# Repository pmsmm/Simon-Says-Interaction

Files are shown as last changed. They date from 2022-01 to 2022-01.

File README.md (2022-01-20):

# Simon Says Interaction

The Simon Says Interaction is a mini game that was developed for my Master Thesis "Developing a Support Infrastructure for an Escape The Room and Peddy Paper Games".

This mini game, or interaction as I so call it, was developed to be part of an Escape the Room game that was also developed as part of my thesis. Since this interaction can work as a standalone mini game I decided to place it here for anyone interested in using it.

## List of Components

- Otemu Mechanical Switch (12x);
- Diode 1n4148 (12x);
- Red LED (1x);
- Green LED (1x);
- Piezzo Speaker (1x);
- 7-Segment Display (1x);
- 220Ω Resistor (10x);
- Arduino Nano (1x);

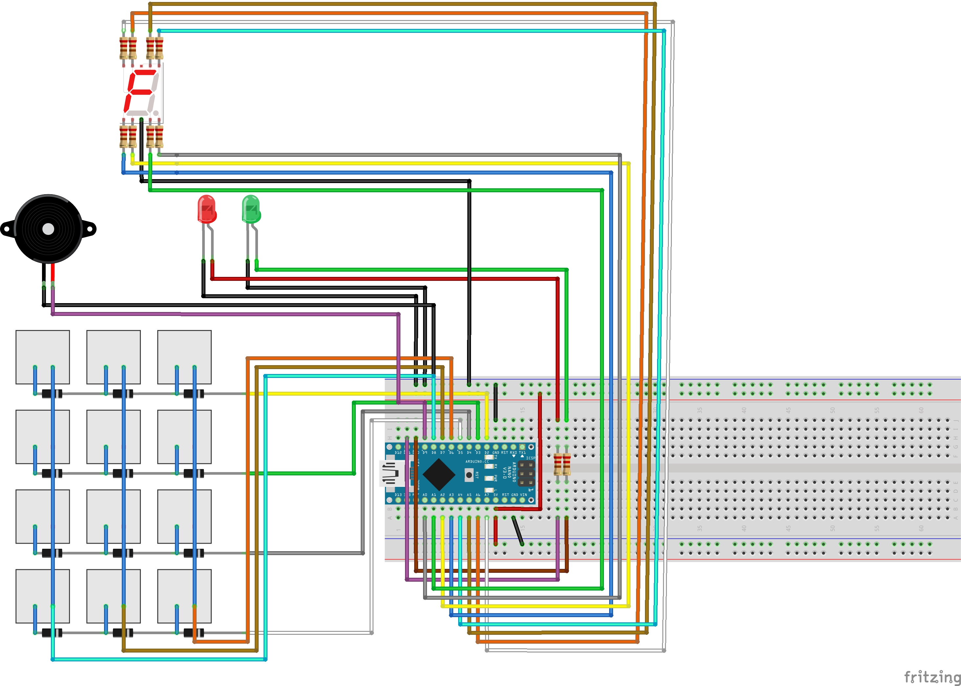
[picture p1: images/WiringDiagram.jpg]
Wiring Diagram


In order to fully assemble the Interaction, so as to look like the picture below, you will also need to 3D Print the enclosure which is divided into two parts that can be found [here](enclosure/). Additionally, you will also need to 3D Print the keycaps which were not designed by me but can be found in [Thingiverse](https://www.thingiverse.com/thing:2783650).

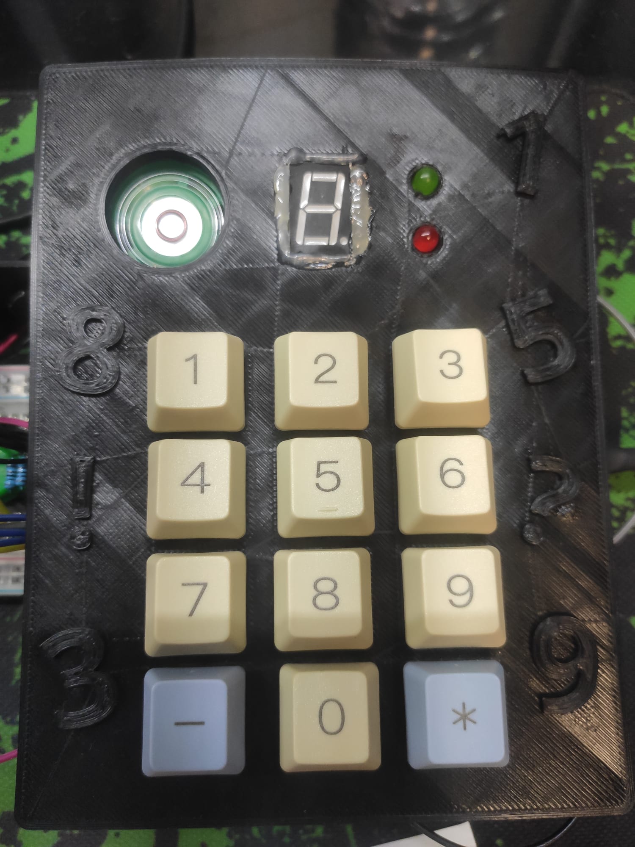
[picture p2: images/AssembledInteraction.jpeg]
Assembled Interaction


## The Purpose of The Game

The Simon Says Interaction is the classic memory game mixed up with pattern recognition in a light sense. The way this mini game works is that on the 7-Segment display, a series of numbers will appear in increasingly hard sequences that have to be reproduced but the tricky part that the player will have to realize is that only the numbers that appear with the dot on the display lit are the ones that should be introduced.

### Example

Lets say for example that the following numbers appear on the display:

- > 7 9. 3 5. 0. 3 6 1.

What the player would have to introduce in order to solve this mini game would be the numbers 9, 5, 0 and 1 in this order. When they achieve this the green LED will light up and a success sound will be played to symbolize that the player has won.

## Intructions 

First start by uploading the code to your Arduino Nano (This is the one I used so I can only guarantee proper working with this micro-controller).

### Starting the Game

To start the game you must first type in the Arduino IDE serial monitor the following:

- > COM:START;ID:123456789

This command will then print in the Serial Monitor the solution of the game which then needs to be introduced using the keypad. If the introduced code is correct then the following message will appear in the serial monitor:

- > COM:INTERACTION_SOLVED;MSG:User Introduced Correct Patterns;PNT:1500

## Warning

The source code for this interaction contains a lot of logic that was made to communicate with the infrastructure that was developed for my thesis and therefor it is not as clean as it could be when compared to a mini game that is developed with the intent of being used by the Arduino IDE directly.

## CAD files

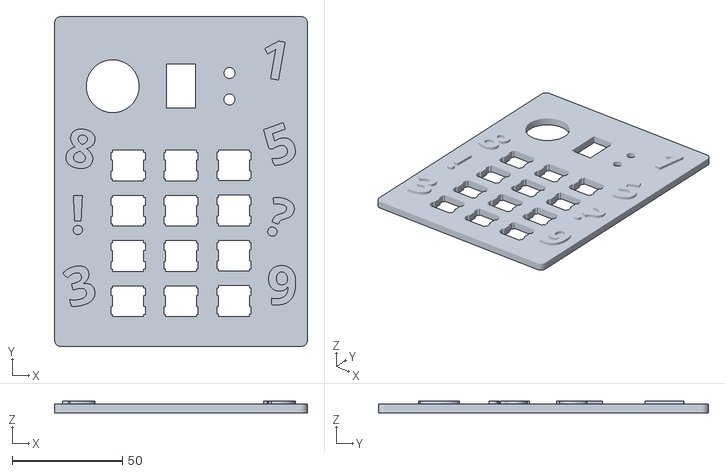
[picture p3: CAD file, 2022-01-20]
enclosure/Simon Says Plate.stl
115.0 x 150.0 x 5.50

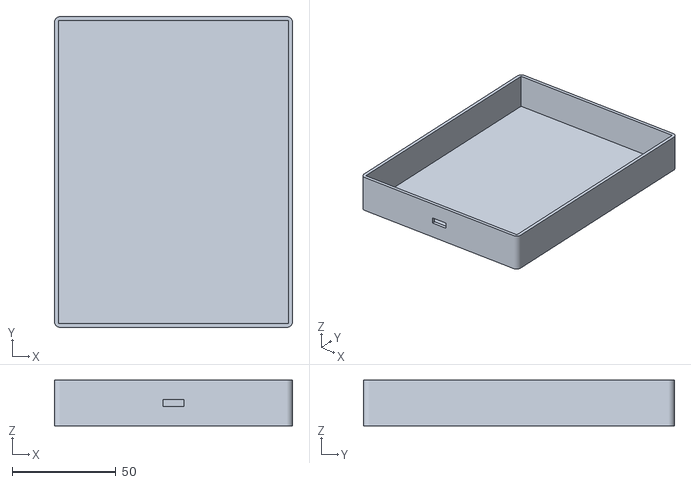
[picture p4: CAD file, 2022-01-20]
enclosure/Simon Says Case.stl
115.0 x 150.0 x 22.0

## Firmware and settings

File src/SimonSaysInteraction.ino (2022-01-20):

#include "pitches.h"
/*
  Displays the numbers 0-9 on the display, at one second intervals
  Implemented using 5611AH - 8-segment display
  Pin assignment for 5611AH
     G  F com A  B
   __|__|__|__|__|__
  | 10  9  8  7  6  |
  |  1  2  3  4  5  |
   --|--|--|--|--|--
     E  D com C  P

  A=7,B=6,C=4,D=2,E=1,F=9,G=10,P=5,com=GND
  LED segment assignment corresponding to pins
    A
   ---
  F |   | B
  | G |
   ---
  E |   | C
  |   |
   ---  . P
    D
*/

const uint8_t pinA = 15;
const uint8_t pinB = 16;
const uint8_t pinC = 11;
const uint8_t pinD = 10;
const uint8_t pinE = 9;
const uint8_t pinF = 14;
const uint8_t pinG = 13;
const uint8_t pinP = 12;
const uint8_t redLED = A3;
const uint8_t greenLED = A4;
const uint8_t buzzer = A5;

byte rows[] = {2, 3, 4};
const int rowCount = sizeof(rows) / sizeof(rows[0]);

byte cols[] = {5, 6, 7, 8};
const int colCount = sizeof(cols) / sizeof(cols[0]);

byte keys[colCount][rowCount];
uint8_t numbers[colCount][rowCount] = {
  {10, 0, 10},
  {7, 8, 9},
  {4, 5, 6},
  {1, 2, 3}
};

struct NUMBER {
  uint8_t number;
  bool isValidNumber;
};

NUMBER firstLevel[4];
NUMBER firstLevelSolution[2];
NUMBER secondLevel[8];
NUMBER secondLevelSolution[4];
NUMBER thirdLevel[12];
NUMBER thirdLevelSolution[6];
NUMBER fourthLevel[16];
NUMBER fourthLevelSolution[8];

uint8_t currentLevel = 1;
uint8_t currentLevelIndex = 0;
bool sequencePlayedOnce = false;

bool INTERACTION_SOLVED, INTERACTION_RUNNING;

void setup() {
  Serial.begin(9600);
  randomSeed(analogRead(A0));
  pinMode(pinA, OUTPUT);
  pinMode(pinB, OUTPUT);
  pinMode(pinC, OUTPUT);
  pinMode(pinD, OUTPUT);
  pinMode(pinE, OUTPUT);
  pinMode(pinF, OUTPUT);
  pinMode(pinG, OUTPUT);
  pinMode(pinP, OUTPUT);
  pinMode(greenLED, OUTPUT);
  pinMode(redLED, OUTPUT);
}

void loop() {
  if (!Serial) {
    Serial.begin(9600);
  }
  if (Serial.available()) {
    processSerialMessage();
  }
  if (INTERACTION_SOLVED == false && INTERACTION_RUNNING == true) {
    gameLoop();
  }
}

void gameLoop() {
  if (!sequencePlayedOnce) {
    Serial.println("Lighting Up Sequence");
    if (currentLevel == 1) {
      Serial.println("Lighting Up Sequence For Level 1");
      for (uint8_t i = 0; i < 4; i++) {
        printNumber(firstLevel[i]);
      }
    }
    else if (currentLevel == 2) {
      Serial.println("Lighting Up Sequence For Level 2");
      for (uint8_t i = 0; i < 8; i++) {
        printNumber(secondLevel[i]);
      }
    }
    else if (currentLevel == 3) {
      Serial.println("Lighting Up Sequence For Level 3");
      for (uint8_t i = 0; i < 12; i++) {
        printNumber(thirdLevel[i]);
      }
    }
    else if (currentLevel == 4) {
      Serial.println("Lighting Up Sequence For Level 4");
      for (uint8_t i = 0; i < 16; i++) {
        printNumber(fourthLevel[i]);
      }
    }
    sequencePlayedOnce = true;
  }
  checkPressedButton(readMatrixAndReturnPressedKey());
  delay(225);
}

void checkPressedButton(int8_t selectedNumber) {
  if (selectedNumber == -1) {
    return;
  }
  NUMBER number;
  number.number = selectedNumber;
  printNumber(number);
  if (currentLevel == 1) {
    if (selectedNumber == firstLevelSolution[currentLevelIndex].number) {
      if (currentLevelIndex == 1) {
        currentLevelIndex = 0;
        currentLevel++;
        sequencePlayedOnce = false;
        digitalWrite(greenLED, HIGH);
        tone(buzzer, NOTE_FS7, 1500);
        delay(1500);
        digitalWrite(greenLED, LOW);
      } else {
        currentLevelIndex++;
      }
    } else {
      sequencePlayedOnce = false;
      digitalWrite(redLED, HIGH);
      tone(buzzer, NOTE_GS2, 1500);
      delay(1500);
      digitalWrite(redLED, LOW);
      currentLevelIndex = 0;
      currentLevel = 1;
    }
  } else if (currentLevel == 2) {
    if (selectedNumber == secondLevelSolution[currentLevelIndex].number) {
      if (currentLevelIndex == 3) {
        currentLevelIndex = 0;
        currentLevel++;
        sequencePlayedOnce = false;
        digitalWrite(greenLED, HIGH);
        tone(buzzer, NOTE_FS7, 1500);
        delay(1500);
        digitalWrite(greenLED, LOW);
      } else {
        currentLevelIndex++;
      }
    } else {
      sequencePlayedOnce = false;
      digitalWrite(redLED, HIGH);
      tone(buzzer, NOTE_GS2, 1500);
      delay(1500);
      digitalWrite(redLED, LOW);
      currentLevelIndex = 0;
      currentLevel = 1;
    }
  } else if (currentLevel == 3) {
    if (selectedNumber == thirdLevelSolution[currentLevelIndex].number) {
      if (currentLevelIndex == 5) {
        currentLevelIndex = 0;
        currentLevel++;
        sequencePlayedOnce = false;
        digitalWrite(greenLED, HIGH);
        tone(buzzer, NOTE_FS7, 1500);
        delay(1500);
        digitalWrite(greenLED, LOW);
      } else {
        currentLevelIndex++;
      }
    } else {
      sequencePlayedOnce = false;
      digitalWrite(redLED, HIGH);
      tone(buzzer, NOTE_GS2, 1500);
      delay(1500);
      digitalWrite(redLED, LOW);
      currentLevelIndex = 0;
      currentLevel = 1;
    }
  } else if (currentLevel == 4) {
    if (selectedNumber == fourthLevelSolution[currentLevelIndex].number) {
      if (currentLevelIndex == 7) {
        currentLevelIndex = 0;
        currentLevel++;
        sequencePlayedOnce = false;
        digitalWrite(greenLED, HIGH);
        tone(buzzer, NOTE_FS7, 1500);
        delay(1500);
        digitalWrite(greenLED, LOW);
        checkWinning();
      } else {
        currentLevelIndex++;
      }
    } else {
      sequencePlayedOnce = false;
      digitalWrite(redLED, HIGH);
      tone(buzzer, NOTE_GS2, 1500);
      delay(1500);
      digitalWrite(redLED, LOW);
      currentLevelIndex = 0;
      currentLevel = 1;
    }
  }
}


void printNumber(NUMBER numberToPrint) {
  Serial.println(numberToPrint.number);
  if (numberToPrint.number == 1) {
    digitalWrite(pinA, LOW);
    digitalWrite(pinB, HIGH);
    digitalWrite(pinC, HIGH);
    digitalWrite(pinD, LOW);
    digitalWrite(pinE, LOW);
    digitalWrite(pinF, LOW);
    digitalWrite(pinG, LOW);
    digitalWrite(pinP, LOW);
  } else if (numberToPrint.number == 2) {
    digitalWrite(pinA, HIGH);
    digitalWrite(pinB, HIGH);
    digitalWrite(pinC, LOW);
    digitalWrite(pinD, HIGH);
    digitalWrite(pinE, HIGH);
    digitalWrite(pinF, LOW);
    digitalWrite(pinG, HIGH);
    digitalWrite(pinP, LOW);
  } else if (numberToPrint.number == 3) {
    digitalWrite(pinA, HIGH);
    digitalWrite(pinB, HIGH);
    digitalWrite(pinC, HIGH);
    digitalWrite(pinD, HIGH);
    digitalWrite(pinE, LOW);
    digitalWrite(pinF, LOW);
    digitalWrite(pinG, HIGH);
    digitalWrite(pinP, LOW);
  } else if (numberToPrint.number == 4) {
    digitalWrite(pinA, LOW);
    digitalWrite(pinB, HIGH);
    digitalWrite(pinC, HIGH);
    digitalWrite(pinD, LOW);
    digitalWrite(pinE, LOW);
    digitalWrite(pinF, HIGH);
    digitalWrite(pinG, HIGH);
    digitalWrite(pinP, LOW);
  } else if (numberToPrint.number == 5) {
    digitalWrite(pinA, HIGH);
    digitalWrite(pinB, LOW);
    digitalWrite(pinC, HIGH);
    digitalWrite(pinD, HIGH);
    digitalWrite(pinE, LOW);
    digitalWrite(pinF, HIGH);
    digitalWrite(pinG, HIGH);
  } else if (numberToPrint.number == 6) {
    digitalWrite(pinA, HIGH);
    digitalWrite(pinB, LOW);
    digitalWrite(pinC, HIGH);
    digitalWrite(pinD, HIGH);
    digitalWrite(pinE, HIGH);
    digitalWrite(pinF, HIGH);
    digitalWrite(pinG, HIGH);
    digitalWrite(pinP, LOW);
  } else if (numberToPrint.number == 7) {
    digitalWrite(pinA, HIGH);
    digitalWrite(pinB, HIGH);
    digitalWrite(pinC, HIGH);
    digitalWrite(pinD, LOW);
    digitalWrite(pinE, LOW);
    digitalWrite(pinF, LOW);
    digitalWrite(pinG, LOW);
    digitalWrite(pinP, LOW);
  } else if (numberToPrint.number == 8) {
    digitalWrite(pinA, HIGH);
    digitalWrite(pinB, HIGH);
    digitalWrite(pinC, HIGH);
    digitalWrite(pinD, HIGH);
    digitalWrite(pinE, HIGH);
    digitalWrite(pinF, HIGH);
    digitalWrite(pinG, HIGH);
    digitalWrite(pinP, LOW);
  } else if (numberToPrint.number == 9) {
    digitalWrite(pinA, HIGH);
    digitalWrite(pinB, HIGH);
    digitalWrite(pinC, HIGH);
    digitalWrite(pinD, HIGH);
    digitalWrite(pinE, LOW);
    digitalWrite(pinF, HIGH);
    digitalWrite(pinG, HIGH);
    digitalWrite(pinP, LOW);
  } else if (numberToPrint.number == 0) {
    digitalWrite(pinA, HIGH);
    digitalWrite(pinB, HIGH);
    digitalWrite(pinC, HIGH);
    digitalWrite(pinD, HIGH);
    digitalWrite(pinE, HIGH);
    digitalWrite(pinF, HIGH);
    digitalWrite(pinG, LOW);
    digitalWrite(pinP, LOW);
  }
  if (numberToPrint.isValidNumber) {
    digitalWrite(pinP, HIGH);
  }
  delay(1000);
  shutdown7SegmentDisplay();
  delay(100);
}

void shutdown7SegmentDisplay() {
  digitalWrite(pinA, LOW);
  digitalWrite(pinB, LOW);
  digitalWrite(pinC, LOW);
  digitalWrite(pinD, LOW);
  digitalWrite(pinE, LOW);
  digitalWrite(pinF, LOW);
  digitalWrite(pinG, LOW);
  digitalWrite(pinP, LOW);
}

void generateRandomNumberStructs(NUMBER numbers[], NUMBER validNumbers[], uint8_t arraySize) {
  uint8_t i = 0;
  for (i = 0; i < arraySize / 2; i++) {
    NUMBER randomNumber;
    randomNumber.number = random(0, 10);
    randomNumber.isValidNumber = true;
    numbers[i] = randomNumber;
  }
  for (i = arraySize / 2; i < arraySize; i++) {
    NUMBER randomNumber;
    randomNumber.number = random(0, 10);
    randomNumber.isValidNumber = false;
    numbers[i] = randomNumber;
  }
  for (i = 0; i < arraySize; i++) {
    uint8_t n = random(0, arraySize);
    NUMBER temp = numbers[n];
    numbers[n] = numbers[i];
    numbers[i] = temp;
  }
  uint8_t solutionArrayIndex = 0;
  for (i = 0; i < arraySize; i++) {
    if (numbers[i].isValidNumber) {
      validNumbers[solutionArrayIndex++] = numbers[i];
    }
  }
}

int8_t readMatrixAndReturnPressedKey() {
  int8_t pressedKey = 100;
  while (pressedKey == 100) {
    // iterate the columns
    for (int colIndex = 0; colIndex < colCount; colIndex++) {
      // col: set to output to low
      byte curCol = cols[colIndex];
      pinMode(curCol, OUTPUT);
      digitalWrite(curCol, LOW);

      // row: interate through the rows
      for (int rowIndex = 0; rowIndex < rowCount; rowIndex++) {
        byte rowCol = rows[rowIndex];
        pinMode(rowCol, INPUT_PULLUP);
        keys[colIndex][rowIndex] = digitalRead(rowCol);
        pinMode(rowCol, INPUT);
      }
      // disable the column
      pinMode(curCol, INPUT);
    }

    for (int colIndex = 0; colIndex < colCount; colIndex++) {
      for (int rowIndex = 0; rowIndex < rowCount; rowIndex++) {
        if (keys[colIndex][rowIndex] == LOW) {
          pressedKey = numbers[colIndex][rowIndex];
        }
      }
    }

    if (Serial.available()) {
      processSerialMessage();
      return -1;
    }

  }

  return pressedKey;

}

void processSerialMessage() {
  const uint8_t BUFF_SIZE = 64; // make it big enough to hold your longest command
  static char buffer[BUFF_SIZE + 1]; // +1 allows space for the null terminator
  static uint8_t length = 0; // number of characters currently in the buffer

  char c = Serial.read();
  if ((c == '\r') || (c == '\n')) {
    // end-of-line received
    if (length > 0) {
      tokenizeReceivedMessage(buffer);
    }
    length = 0;
  } else {
    if (length < BUFF_SIZE) {
      buffer[length++] = c; // append the received character to the array
      buffer[length] = 0; // append the null terminator
    }
  }
}

void tokenizeReceivedMessage(char *msg) {
  const uint8_t COMMAND_PAIRS = 10;
  char* tokenizedString[COMMAND_PAIRS + 1];
  uint8_t index = 0;

  char* command = strtok(msg, ";");
  while (command != 0) {
    char* separator = strchr(command, ':');
    if (separator != 0) {
      *separator = 0;
      tokenizedString[index++] = command;
      ++separator;
      tokenizedString[index++] = separator;
    }
    command = strtok(0, ";");
  }
  tokenizedString[index] = 0;

  processReceivedMessage(tokenizedString);
}

void processReceivedMessage(char** command) {
  if (strcmp(command[1], "START") == 0) {
    startSequence(command[3]);
  } else if (strcmp(command[1], "PAUSE") == 0) {
    pauseSequence(command[3]);
  } else if (strcmp(command[1], "STOP") == 0) {
    stopSequence(command[3]);
  } else if (strcmp(command[1], "INTERACTION_SOLVED_ACK") == 0) {
    setInteractionSolved();
  } else if (strcmp(command[1], "PING") == 0) {
    ping(command[3]);
  } else if (strcmp(command[1], "BAUD") == 0) {
    setBaudRate(atoi(command[3]), command[5]);
  } else if (strcmp(command[1], "SETUP") == 0) {
    Serial.println("COM:SETUP;INT_NAME:Simon Says Interaction;BAUD:9600");
    Serial.flush();
  }
}

//TODO: Review This Method once Interaction Is Completed
void startSequence(char* TIMESTAMP) {
  INTERACTION_SOLVED = false;
  INTERACTION_RUNNING = true;
  generateRandomNumberStructs(firstLevel, firstLevelSolution, 4);
  generateRandomNumberStructs(secondLevel, secondLevelSolution, 8);
  generateRandomNumberStructs(thirdLevel, thirdLevelSolution, 12);
  generateRandomNumberStructs(fourthLevel, fourthLevelSolution, 16);
  currentLevel = 1;
  currentLevelIndex = 0;
  sequencePlayedOnce = false;
  Serial.print("COM:START_ACK;MSG:");
  Serial.print("L1-");
  for (uint8_t i = 0; i < 2; i++) {
    Serial.print(firstLevelSolution[i].number);
  }
  Serial.print("L2-");
  for (uint8_t i = 0; i < 4; i++) {
    Serial.print(secondLevelSolution[i].number);
  }
  Serial.print("L3-");
  for (uint8_t i = 0; i < 6; i++) {
    Serial.print(thirdLevelSolution[i].number);
  }
  Serial.print("L4-");
  for (uint8_t i = 0; i < 8; i++) {
    Serial.print(fourthLevelSolution[i].number);
  }
  Serial.print(";ID:");
  Serial.print(TIMESTAMP);
  Serial.print("\r\n");
  Serial.flush();
}

void pauseSequence(char* TIMESTAMP) {
  INTERACTION_RUNNING = !INTERACTION_RUNNING;
  if (INTERACTION_RUNNING) {
    Serial.print("COM:PAUSE_ACK;MSG:Device is now running;ID:");
  } else {
    Serial.print("COM:PAUSE_ACK;MSG:Device is now paused;ID:");
  }
  Serial.print(TIMESTAMP);
  Serial.print("\r\n");
  Serial.flush();
}

void stopSequence(char* TIMESTAMP) {
  INTERACTION_RUNNING = false;
  Serial.print("COM:STOP_ACK;MSG:Device is now stopped;ID:");
  Serial.print(TIMESTAMP);
  Serial.print("\r\n");
  Serial.flush();
}

void setInteractionSolved() {
  INTERACTION_SOLVED = true;
  INTERACTION_RUNNING = false;
}

void ping(char* TIMESTAMP) {
  Serial.print("COM:PING;MSG:PING;ID:");
  Serial.print(TIMESTAMP);
  Serial.print("\r\n");
  Serial.flush();
}

void setBaudRate(int baudRate, char* TIMESTAMP) {
  Serial.flush();
  Serial.begin(baudRate);
  Serial.print("COM:BAUD_ACK;MSG:The Baud Rate was set to ");
  Serial.print(baudRate);
  Serial.print(";ID:");
  Serial.print(TIMESTAMP);
  Serial.print("\r\n");
  Serial.flush();
}

bool checkWinning() {
  setInteractionSolved();
  Serial.println("COM:INTERACTION_SOLVED;MSG:User Introduced Correct Patterns;PNT:1500");
  Serial.flush();

  int NOTE_SUSTAIN = 85;
  tone(buzzer, NOTE_A5);
  delay(NOTE_SUSTAIN);
  tone(buzzer, NOTE_B5);
  delay(NOTE_SUSTAIN);
  tone(buzzer, NOTE_C5);
  delay(NOTE_SUSTAIN);
  tone(buzzer, NOTE_B5);
  delay(NOTE_SUSTAIN);
  tone(buzzer, NOTE_C5);
  delay(NOTE_SUSTAIN);
  tone(buzzer, NOTE_D5);
  delay(NOTE_SUSTAIN);
  tone(buzzer, NOTE_C5);
  delay(NOTE_SUSTAIN);
  tone(buzzer, NOTE_D5);
  delay(NOTE_SUSTAIN);
  tone(buzzer, NOTE_E5);
  delay(NOTE_SUSTAIN);
  tone(buzzer, NOTE_D5);
  delay(NOTE_SUSTAIN);
  tone(buzzer, NOTE_E5);
  delay(NOTE_SUSTAIN);
  tone(buzzer, NOTE_E5);
  delay(NOTE_SUSTAIN);
  noTone(buzzer);

  digitalWrite(pinA, HIGH);
  digitalWrite(pinB, HIGH);
  digitalWrite(pinC, HIGH);
  digitalWrite(pinD, HIGH);
  digitalWrite(pinE, HIGH);
  digitalWrite(pinF, HIGH);
  digitalWrite(pinG, HIGH);
  digitalWrite(pinP, HIGH);

  delay(1000);

  digitalWrite(pinA, LOW);
  digitalWrite(pinB, LOW);
  digitalWrite(pinC, LOW);
  digitalWrite(pinD, LOW);
  digitalWrite(pinE, LOW);
  digitalWrite(pinF, LOW);
  digitalWrite(pinG, LOW);
  digitalWrite(pinP, LOW);

  delay(1000);

  digitalWrite(pinA, HIGH);
  digitalWrite(pinB, HIGH);
  digitalWrite(pinC, HIGH);
  digitalWrite(pinD, HIGH);
  digitalWrite(pinE, HIGH);
  digitalWrite(pinF, HIGH);
  digitalWrite(pinG, HIGH);
  digitalWrite(pinP, HIGH);

  delay(1000);

  digitalWrite(pinA, LOW);
  digitalWrite(pinB, LOW);
  digitalWrite(pinC, LOW);
  digitalWrite(pinD, LOW);
  digitalWrite(pinE, LOW);
  digitalWrite(pinF, LOW);
  digitalWrite(pinG, LOW);
  digitalWrite(pinP, LOW);
}
